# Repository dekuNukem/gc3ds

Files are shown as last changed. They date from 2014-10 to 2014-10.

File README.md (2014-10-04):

gc3ds is a 3DS modification that allows user to use Nintendo GameCube controller to play any games on Nintendo 3DS consoles. This open-source project uses an Arduino Nano to read the state of GameCube controller, then mirror them to Nintendo 3DS with a maximum delay of no more than 1/1000 seconds (1 millisecond). Users can also choose to customize button mappings between gc controller and 3DS with a LCD screen. 

For all the resources about this project(video, parts list, guides, etc), see http://goo.gl/SyRLb5

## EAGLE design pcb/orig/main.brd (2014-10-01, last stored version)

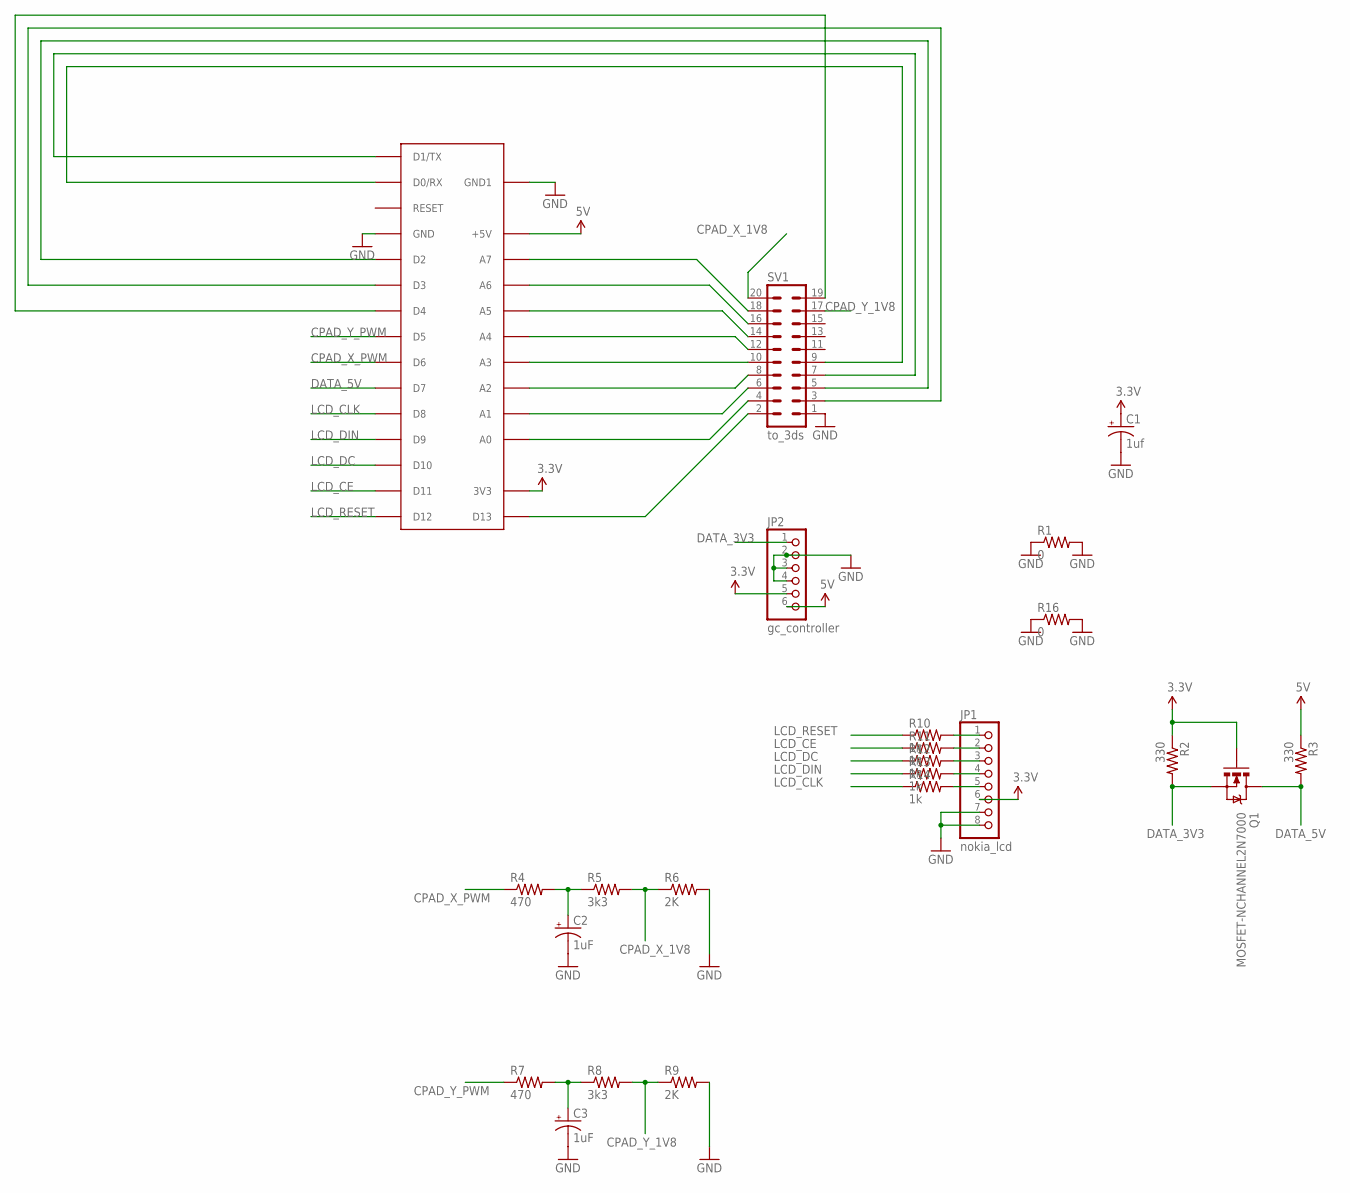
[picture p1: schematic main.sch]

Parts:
C1: 1uf; CPOL-RADIAL-10UF-25V
C2, C3: 1uF; CPOL-RADIAL-10UF-25V
JP1: nokia_lcd; 1X08-CLEANBIG
JP2: gc_controller; 1X06
Q1: MOSFET-NCHANNEL2N7000; TO-92
R1, R16: 0; AXIAL-0.4
R2, R3: 330; AXIAL-0.4
R4, R7: 470; AXIAL-0.4
R5, R8: 3k3; AXIAL-0.4
R6, R9: 2K; AXIAL-0.4
R10, R11, R12, R13, R14: 1k; AXIAL-0.4
SV1: to_3ds; MA10-2
U$1: ARDUINONANO; PDIP-32

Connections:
3.3V: C1.1 (+), JP1.6, JP2.5, Q1.2 (G), R2.P$1 (1), U$1.3V3
5V: JP2.6, R3.P$1 (1), U$1.+5V
CPAD_X_1V8: R5.P$2 (2), R6.P$1 (1), SV1.20
CPAD_X_PWM: R4.P$1 (1), U$1.D6
CPAD_Y_1V8: R8.P$2 (2), R9.P$1 (1), SV1.17
CPAD_Y_PWM: R7.P$1 (1), U$1.D5
DATA_3V3: JP2.1, Q1.1 (S), R2.P$2 (2)
DATA_5V: Q1.3 (D), R3.P$2 (2), U$1.D7
GND: C1.2 (-), C2.2 (-), C3.2 (-), JP1.7, JP1.8, JP2.2, JP2.3, JP2.4, R1.P$1 (1), R1.P$2 (2), R6.P$2 (2), R9.P$2 (2), R16.P$1 (1), R16.P$2 (2), SV1.1, U$1.GND, U$1.GND1
LCD_CE: R11.P$1 (1), U$1.D11
LCD_CLK: R14.P$1 (1), U$1.D8
LCD_DC: R12.P$1 (1), U$1.D10
LCD_DIN: R13.P$1 (1), U$1.D9
LCD_RESET: R10.P$1 (1), U$1.D12
unnamed: C2.1 (+), R4.P$2 (2), R5.P$1 (1)
unnamed: JP1.1, R10.P$2 (2)
unnamed: JP1.2, R11.P$2 (2)
unnamed: JP1.3, R12.P$2 (2)
unnamed: C3.1 (+), R7.P$2 (2), R8.P$1 (1)
unnamed: JP1.4, R13.P$2 (2)
unnamed: JP1.5, R14.P$2 (2)
unnamed: SV1.2, U$1.D13
unnamed: SV1.4, U$1.A0
unnamed: SV1.6, U$1.A1
unnamed: SV1.8, U$1.A2
unnamed: SV1.10, U$1.A3
unnamed: SV1.12, U$1.A4
unnamed: SV1.14, U$1.A5
unnamed: SV1.16, U$1.A6
unnamed: SV1.18, U$1.A7
unnamed: SV1.19, U$1.D4
unnamed: SV1.3, U$1.D3
unnamed: SV1.5, U$1.D2
unnamed: SV1.7, U$1.D1/TX
unnamed: SV1.9, U$1.D0/RX

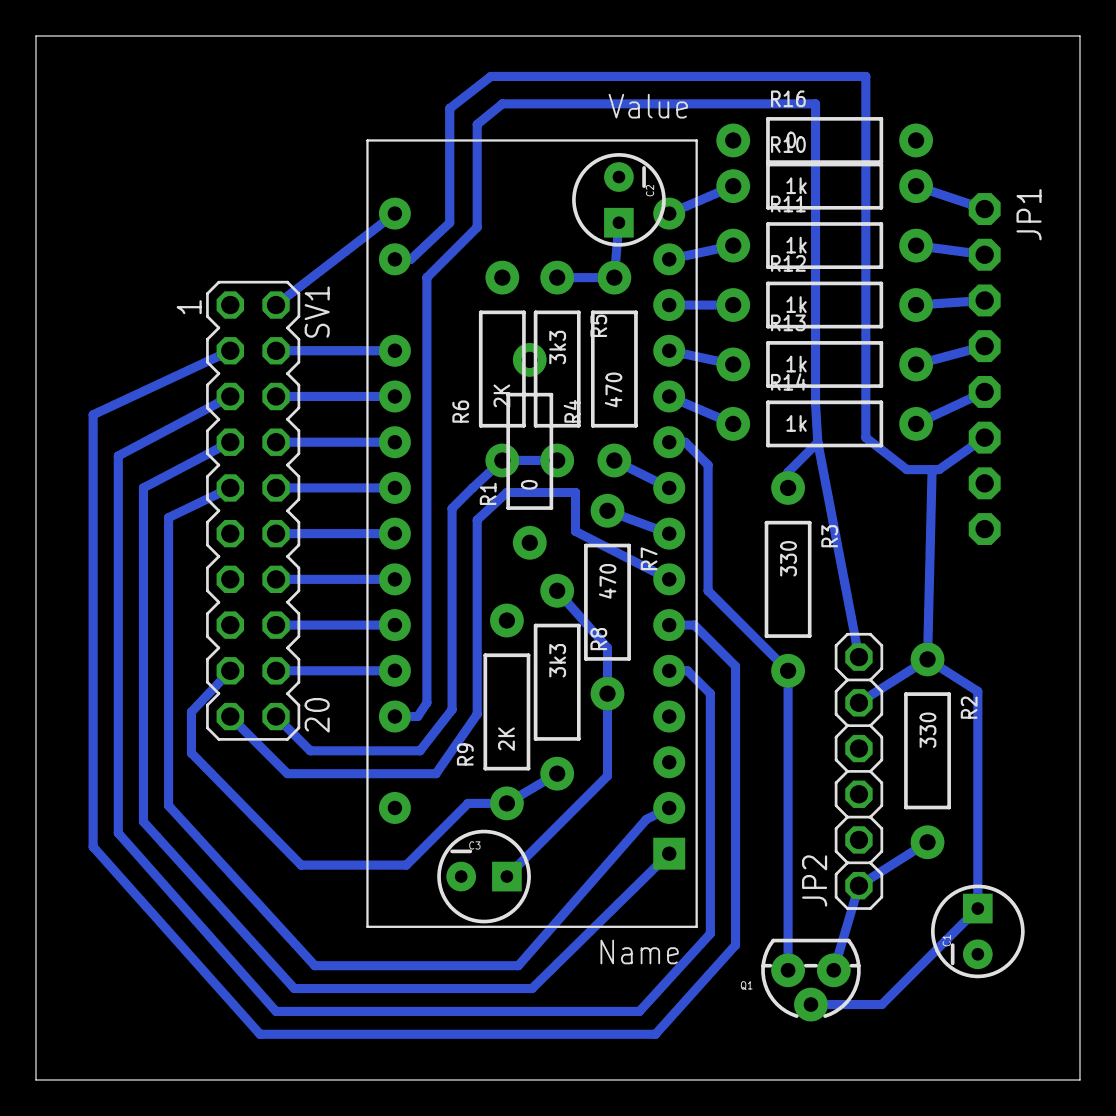
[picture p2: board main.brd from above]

Board: 2 copper layers, 58.0 x 58.0 mm, 23 parts (0 on the bottom side), 35 nets.

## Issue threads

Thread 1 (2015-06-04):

New 3ds?

ryanknutson, 2015-06-04:
Does this work on the New 3ds?

trevor403, 2015-06-09:
Technically, because this is not a software hack, it's a hardware hack. All you need to do is find the right test points. So yes is the short answer, but no because it has a new circuit board.

ryanknutson, 2015-06-12:
Is there any mapping for the new test points? I don't have a New 3ds yet so I can't look.

acasaro, 2015-06-18:
I have a new 3DS XL and I can try to help if you point me in the right direction.  I'm currently trying to confirm if there are any difference in setup between the two before I start the mod.

acasaro, 2015-06-18:
Never mind, he includes the new as well in his google doc. https://docs.google.com/document/d/1-dCfkwnoIebxSwfW9gZ9NFpktMHbVTEVkIrduLGLTMM/mobilebasic?pli=1

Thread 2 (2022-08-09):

Some questions regarding voltages

lipe-dev, 2022-08-09:
Hey @dekuNukem! How is it going?

I have some questions regarding this project, and for full disclosure, it is because I'm working on my own version of it.

- Do you feed the arduino logic outputs straight into the 3DS test pads? Do they expect the full 5V? or do you step them down?
- I'm trying to make do with a Pro Micro, because I have them in hand, and it lacks 3.3V output, are you aware if the 3ds is able to provide such voltages? I want to avoid ordering a step down voltage regulator if I can help it.
- Do you have any resource where I can find data on the new 3ds voltages and test pads?

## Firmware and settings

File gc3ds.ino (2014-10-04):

#define DATA_PIN 7
#define CPAD_X_PIN 5
#define CPAD_Y_PIN 6
#include <EEPROM.h>
#include "Nintendo.h"
#include "nokia_lcd.h"
#include "ds_pindef.h"
#include "setting_menu.h"
#include <stdlib.h>

void setup()
{
	ds_pin_init();
	map_init();
	pinMode(CPAD_X_PIN, OUTPUT);
	pinMode(CPAD_Y_PIN, OUTPUT);	
	analogWrite(CPAD_X_PIN, 30);
	analogWrite(CPAD_Y_PIN, 200);
	lcd.clear();
	lcd.gotoXY(0, 0);
	lcd.print("waiting for");
	lcd.gotoXY(0, 2);
	lcd.print("GameCube");
	lcd.gotoXY(0, 4);
	lcd.print("controller");

	// wait for gc controller 
	while(Gamecube.begin(DATA_PIN) == false);

	// go into settings menu if gc controllerstart button is held down
	if(Gamecube.read(false) && Gamecube.report.start == 1)
		do_menu();

	lcd.clear();
	lcd.gotoXY(0, 0);
	lcd.print("controller");
	lcd.gotoXY(0, 1);
	lcd.print("found");
	/* 
		switching timer0 prescaler to 1 so that PWM frequency on pin 5 and 6
		is 62.5KHz, making it easier to filter.
		for details see: http://playground.arduino.cc/Main/TimerPWMCheatsheet
	*/
	TCCR0B = TCCR0B & 0b11111000 | 0x01;
}

void map_button(char gc_index)
{
	// find the corresponding 3DS index, given gc controller index
	char ds_index = ds_button_map[gc_index];

	if(ds_index < 0 || ds_index > 7)
		return;
	
	// if any of its mappings is 1, press that button
	for(int i = 0; i < 10; i++)
		if(ds_button_map[i] == ds_index && gc_report[i])
		{
			button_control(ds_pin_map[ds_index], 1);
			return;
		}

	button_control(ds_pin_map[ds_index], 0);
}


void loop()
{
	read_gc_controller();

	gc_report[GC_A_BUTTON] = Gamecube.report.a;
	gc_report[GC_B_BUTTON] = Gamecube.report.b;
	gc_report[GC_X_BUTTON] = Gamecube.report.x;
	gc_report[GC_Y_BUTTON] = Gamecube.report.y;
	gc_report[GC_L_TRIGGER] = Gamecube.report.left > 127;
	gc_report[GC_L_BUTTON] = Gamecube.report.l;
	gc_report[GC_R_TRIGGER] = Gamecube.report.right > 127;
	gc_report[GC_R_BUTTON] = Gamecube.report.r;
	gc_report[GC_Z_BUTTON] = Gamecube.report.z;
	gc_report[GC_START_BUTTON] = Gamecube.report.start;

	map_button(GC_A_BUTTON);
	map_button(GC_B_BUTTON);
	map_button(GC_X_BUTTON);
	map_button(GC_Y_BUTTON);
	map_button(GC_L_TRIGGER);
	map_button(GC_L_BUTTON);
	map_button(GC_R_TRIGGER);
	map_button(GC_R_BUTTON);
	map_button(GC_Z_BUTTON);
	map_button(GC_START_BUTTON);

	if(is_c_stick_smash_enabled)
	{
		while((Gamecube.report.cxAxis < 100 && Gamecube.report.cxAxis > 80) || 
			(Gamecube.report.cxAxis > 150 && Gamecube.report.cxAxis < 170) || 
			(Gamecube.report.cyAxis < 100 && Gamecube.report.cyAxis > 80) || 
			(Gamecube.report.cyAxis > 150 && Gamecube.report.cyAxis < 170))
		{
			read_gc_controller();
			analogWrite(CPAD_X_PIN, (int)(127));
			analogWrite(CPAD_Y_PIN, (int)(127));
			button_control(DS_A_PIN, 0);
		}

		while(Gamecube.report.cxAxis < 80 || Gamecube.report.cxAxis > 170 || Gamecube.report.cyAxis > 170 || Gamecube.report.cyAxis < 80)
		{
			read_gc_controller();

			//  left samsh
			if(Gamecube.report.cxAxis < 80)
			{
				analogWrite(CPAD_X_PIN, (int)(255));
				analogWrite(CPAD_Y_PIN, (int)(127));
			}

			//  right samsh
			else if(Gamecube.report.cxAxis > 170)
			{
				analogWrite(CPAD_X_PIN, (int)(0));
				analogWrite(CPAD_Y_PIN, (int)(127));
			}

			//  up samsh
			else if(Gamecube.report.cyAxis > 170)
			{
				analogWrite(CPAD_X_PIN, (int)(127));
				analogWrite(CPAD_Y_PIN, (int)(255));
			}

			//  down samsh
			else
			{
				analogWrite(CPAD_X_PIN, (int)(127));
				analogWrite(CPAD_Y_PIN, (int)(0));
			}
			
			button_control(DS_A_PIN, 1);
		}
	}
	else
	{
		// if GC main stick is mapped to 3DS's circle pad
		if(ds_button_map[GC_MAIN_STICK] == DS_CIRCLE_PAD)
		{
			analogWrite(CPAD_X_PIN, (int)(255 - Gamecube.report.xAxis));
			analogWrite(CPAD_Y_PIN, (int)(Gamecube.report.yAxis));
		}
		
		// if GC c-stick is mapped to 3DS's circle pad
		if(ds_button_map[GC_C_STICK] == DS_CIRCLE_PAD)
		{
			analogWrite(CPAD_X_PIN, (int)(255 - Gamecube.report.cxAxis));
			analogWrite(CPAD_Y_PIN, (int)(Gamecube.report.cyAxis));
		}
	}

	// if GC main stick is mapped to 3DS's circle pad
	if(ds_button_map[GC_MAIN_STICK] == DS_CIRCLE_PAD)
	{
		analogWrite(CPAD_X_PIN, (int)(255 - Gamecube.report.xAxis));
		analogWrite(CPAD_Y_PIN, (int)(Gamecube.report.yAxis));
	}

	// if GC main stick is mapped to 3DS d-pad
	if(ds_button_map[GC_MAIN_STICK] == DS_DPAD)
	{
		button_control(DS_DPAD_LEFT_PIN, Gamecube.report.xAxis < 80);
		button_control(DS_DPAD_RIGHT_PIN, Gamecube.report.xAxis > 180);
		button_control(DS_DPAD_UP_PIN, Gamecube.report.yAxis > 170);
		button_control(DS_DPAD_DOWN_PIN, Gamecube.report.yAxis < 70);
	}

	// if GC d-pad is mapped to 3DS's circle pad
	// why would anyone do this? Not implemented.
	if(ds_button_map[GC_DPAD] == DS_CIRCLE_PAD)
	{
		analogWrite(CPAD_X_PIN, 127);
		analogWrite(CPAD_Y_PIN, 127);
	}

	// if GC d-pad is mapped to 3DS d-pad
	if(ds_button_map[GC_DPAD] == DS_DPAD)
	{
		button_control(DS_DPAD_UP_PIN, Gamecube.report.dup);
		button_control(DS_DPAD_DOWN_PIN, Gamecube.report.ddown);
		button_control(DS_DPAD_LEFT_PIN, Gamecube.report.dleft);
		button_control(DS_DPAD_RIGHT_PIN, Gamecube.report.dright);
	}

	// if GC c-stick is mapped to 3DS d-pad
	if(ds_button_map[GC_C_STICK] == DS_DPAD)
	{
		button_control(DS_DPAD_LEFT_PIN, Gamecube.report.cxAxis < 80);
		button_control(DS_DPAD_RIGHT_PIN, Gamecube.report.cxAxis > 180);
		button_control(DS_DPAD_UP_PIN, Gamecube.report.cyAxis > 170);
		button_control(DS_DPAD_DOWN_PIN, Gamecube.report.cyAxis < 70);
	}

	// if GC c-stick is mapped to 3DS's circle pad
	if(ds_button_map[GC_C_STICK] == DS_CIRCLE_PAD)
	{
		analogWrite(CPAD_X_PIN, (int)(255 - Gamecube.report.cxAxis));
		analogWrite(CPAD_Y_PIN, (int)(Gamecube.report.cyAxis));
	}

}

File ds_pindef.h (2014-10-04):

#define DS_A_PIN 13
#define DS_B_PIN A0
#define DS_X_PIN A1
#define DS_Y_PIN A2
#define DS_L_PIN A3
#define DS_R_PIN A4
#define DS_DPAD_UP_PIN A5
#define DS_DPAD_DOWN_PIN 4
#define DS_DPAD_LEFT_PIN 3
#define DS_DPAD_RIGHT_PIN 2
#define DS_START_PIN 0
#define DS_SELECT_PIN -1

char ds_pin_map[8] = {DS_A_PIN, DS_B_PIN, DS_X_PIN, DS_Y_PIN, DS_L_PIN, DS_R_PIN, DS_START_PIN, DS_SELECT_PIN};

void ds_pin_init()
{
	pinMode(DS_A_PIN, INPUT);
	pinMode(DS_B_PIN, INPUT);
	pinMode(DS_X_PIN, INPUT);
	pinMode(DS_Y_PIN, INPUT);
	pinMode(DS_L_PIN, INPUT);
	pinMode(DS_R_PIN, INPUT);
	pinMode(DS_DPAD_UP_PIN, INPUT);
	pinMode(DS_DPAD_DOWN_PIN, INPUT);
	pinMode(DS_DPAD_LEFT_PIN, INPUT);
	pinMode(DS_DPAD_RIGHT_PIN, INPUT);
	pinMode(DS_START_PIN, INPUT);
	pinMode(DS_SELECT_PIN, INPUT);
}

// pull a pin to ground to press a button
void button_control(char pin, char state)
{
	if(pin < 0)
		return;

	if(state == 0)
		pinMode(pin, INPUT);
	else
	{
		pinMode(pin, OUTPUT);
		digitalWrite(pin, LOW);
	}
}

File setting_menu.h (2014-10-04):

#define UNDEFINED -1
#define GC_A_BUTTON 0
#define GC_B_BUTTON 1
#define GC_X_BUTTON 2
#define GC_Y_BUTTON 3
#define GC_L_TRIGGER 4
#define GC_L_BUTTON 5
#define GC_R_TRIGGER 6
#define GC_R_BUTTON 7
#define GC_Z_BUTTON 8
#define GC_START_BUTTON 9
#define GC_MAIN_STICK 10
#define GC_DPAD 11
#define GC_C_STICK 12
#define DS_A_BUTTON 0
#define DS_B_BUTTON 1
#define DS_X_BUTTON 2
#define DS_Y_BUTTON 3
#define DS_L_BUTTON 4
#define DS_R_BUTTON 5
#define DS_START_BUTTON 6
#define DS_SELECT_BUTTON 7
#define DS_CIRCLE_PAD 8
#define DS_DPAD 9
#define BUF_SIZE 13
#define C_STICK_SMASH_ENABLED_EEPROM_ADDR 255

nokia_lcd lcd(12, 11, 10, 9, 8, 193);
char ds_button_map[13];
char print_buf[BUF_SIZE];
char gc_report[10];
char is_c_stick_smash_enabled = 1; 
void do_remap();
void sel_3ds_button(char remap_menu_pos);

/*
	prepare to witness some truly messy code
	I wrote this while staying up late and being a little drunk :)
	but I think it works
*/

void get_ds_name(char index, char* buf)
{
	for(int i = 0; i < BUF_SIZE; i++)
		buf[i] = 0;

	switch(index)
	{
		case DS_A_BUTTON:
		sprintf(buf, "A button  ");
		break;

		case DS_B_BUTTON:
		sprintf(buf, "B button  ");
		break;

		case DS_X_BUTTON:
		sprintf(buf, "X button  ");
		break;

		case DS_Y_BUTTON:
		sprintf(buf, "Y button  ");
		break;

		case DS_L_BUTTON:
		sprintf(buf, "L button  ");
		break;

		case DS_R_BUTTON:
		sprintf(buf, "R button  ");
		break;

		case DS_START_BUTTON:
		sprintf(buf, "start btn ");
		break;

		case DS_SELECT_BUTTON:
		sprintf(buf, "selct btn ");
		break;

		case DS_CIRCLE_PAD:
		sprintf(buf, "circlePad ");
		break;

		case DS_DPAD:
		sprintf(buf, "d-pad     ");
		break;

		case UNDEFINED:
		case 127:
		sprintf(buf, "unmapped  ");
		break;

		default:
		sprintf(buf, "ds err %d", index);
		break;
	}
}

void get_gc_name(char index, char* buf)
{

	for(int i = 0; i < BUF_SIZE; i++)
		buf[i] = 0;

	switch(index)
	{
		case GC_A_BUTTON:
		sprintf(buf, "A button  ");
		break;

		case GC_B_BUTTON:
		sprintf(buf, "B button  ");
		break;

		case GC_X_BUTTON:
		sprintf(buf, "X button  ");
		break;

		case GC_Y_BUTTON:
		sprintf(buf, "Y button  ");
		break;

		case GC_L_TRIGGER:
		sprintf(buf, "L trigger ");
		break;

		case GC_L_BUTTON:
		sprintf(buf, "L button  ");
		break;

		case GC_R_TRIGGER:
		sprintf(buf, "R trigger ");
		break;

		case GC_R_BUTTON:
		sprintf(buf, "R button  ");
		break;

		case GC_Z_BUTTON:
		sprintf(buf, "Z button ");
		break;

		case GC_START_BUTTON:
		sprintf(buf, "start btn ");
		break;

		case GC_MAIN_STICK:
		sprintf(buf, "main stick");
		break;

		case GC_DPAD:
		sprintf(buf, "d-pad     ");
		break;

		case GC_C_STICK:
		sprintf(buf, "c stick   ");
		break;

		default:
		sprintf(buf, "gc err %d", index);
		break;
	}
}

void map_init()
{
	for(int i = 0; i < 13; i++)
		ds_button_map[i] = EEPROM.read(i);
	is_c_stick_smash_enabled = EEPROM.read(C_STICK_SMASH_ENABLED_EEPROM_ADDR);
}

void mapping_reset()
{
	EEPROM.write(GC_A_BUTTON, DS_A_BUTTON);
	EEPROM.write(GC_B_BUTTON, DS_B_BUTTON);
	EEPROM.write(GC_X_BUTTON, DS_X_BUTTON);
	EEPROM.write(GC_Y_BUTTON, DS_Y_BUTTON);
	EEPROM.write(GC_L_TRIGGER, DS_L_BUTTON);
	EEPROM.write(GC_L_BUTTON, DS_L_BUTTON);
	EEPROM.write(GC_R_TRIGGER, DS_R_BUTTON);
	EEPROM.write(GC_R_BUTTON, DS_R_BUTTON);
	EEPROM.write(GC_Z_BUTTON, UNDEFINED);
	EEPROM.write(GC_START_BUTTON, DS_START_BUTTON);
	EEPROM.write(GC_MAIN_STICK, DS_CIRCLE_PAD);
	EEPROM.write(GC_DPAD, DS_DPAD);
	EEPROM.write(GC_C_STICK, UNDEFINED);
	EEPROM.write(C_STICK_SMASH_ENABLED_EEPROM_ADDR, 0);
}

void read_gc_controller()
{
	if(Gamecube.read(false))
		return;
	else
	{
		analogWrite(CPAD_X_PIN, (int)(127));
		analogWrite(CPAD_Y_PIN, (int)(127));
		lcd.clear();
		lcd.gotoXY(0, 0);
		lcd.print("connect");
		lcd.gotoXY(0, 2);
		lcd.print("GameCube");
		lcd.gotoXY(0, 4);
		lcd.print("controller");
		while(Gamecube.begin(DATA_PIN) == false);
		lcd.clear();
		lcd.gotoXY(0, 0);
		lcd.print("controller");
		lcd.gotoXY(0, 1);
		lcd.print("found");
	}
}

bool unique_press_a()
{
	Gamecube.read(false);
	if(Gamecube.report.a == 1)
	{
		while(Gamecube.report.a == 1)
			Gamecube.read(false);
		return true;
	}
	else
		return false;
}

bool unique_press_b()
{
	Gamecube.read(false);
	if(Gamecube.report.b == 1)
	{
		while(Gamecube.report.b == 1)
			Gamecube.read(false);
		return true;
	}
	else
		return false;
}

bool unique_press_left()
{
	Gamecube.read(false);
	if(Gamecube.report.dleft == 1)
	{
		while(Gamecube.report.dleft == 1)
			Gamecube.read(false);
		return true;
	}
	else
		return false;
}

bool unique_press_right()
{
	Gamecube.read(false);
	if(Gamecube.report.dright == 1)
	{
		while(Gamecube.report.dright == 1)
			Gamecube.read(false);
		return true;
	}
	else
		return false;
}
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

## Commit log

2014-10-01 updated low pass filter
    [main.brd, main.sch]
2014-10-04 added s-stick side smash and many-to-one button mapping
2014-10-07 built-in c-pad selector
    [main.brd, main.sch]
2014-10-07 build-in c-pad selector cleaned up
    [main.brd, main.sch]

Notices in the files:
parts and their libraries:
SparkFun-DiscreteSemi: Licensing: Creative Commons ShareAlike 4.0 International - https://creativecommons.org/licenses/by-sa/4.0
